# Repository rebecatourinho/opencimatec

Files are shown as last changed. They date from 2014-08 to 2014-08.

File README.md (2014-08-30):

opencimatec
===========

Neste repositório encontram-se os arquivos referentes ao projeto open source hardware (OSH) do sistema embarcado voltado à instrumentação eletrônica proposto e desenvolvido pela engenheira eletricista Rebeca Tourinho do SENAI CIMATEC - Salvador, Brasil.

In this repository can be found all project files of the open source hardware (OSH) electronics instrumentation embedded system suggested and developed by Rebeca Tourinho, electrical engineer of SENAI CIMATEC - Salvador, Brazil.

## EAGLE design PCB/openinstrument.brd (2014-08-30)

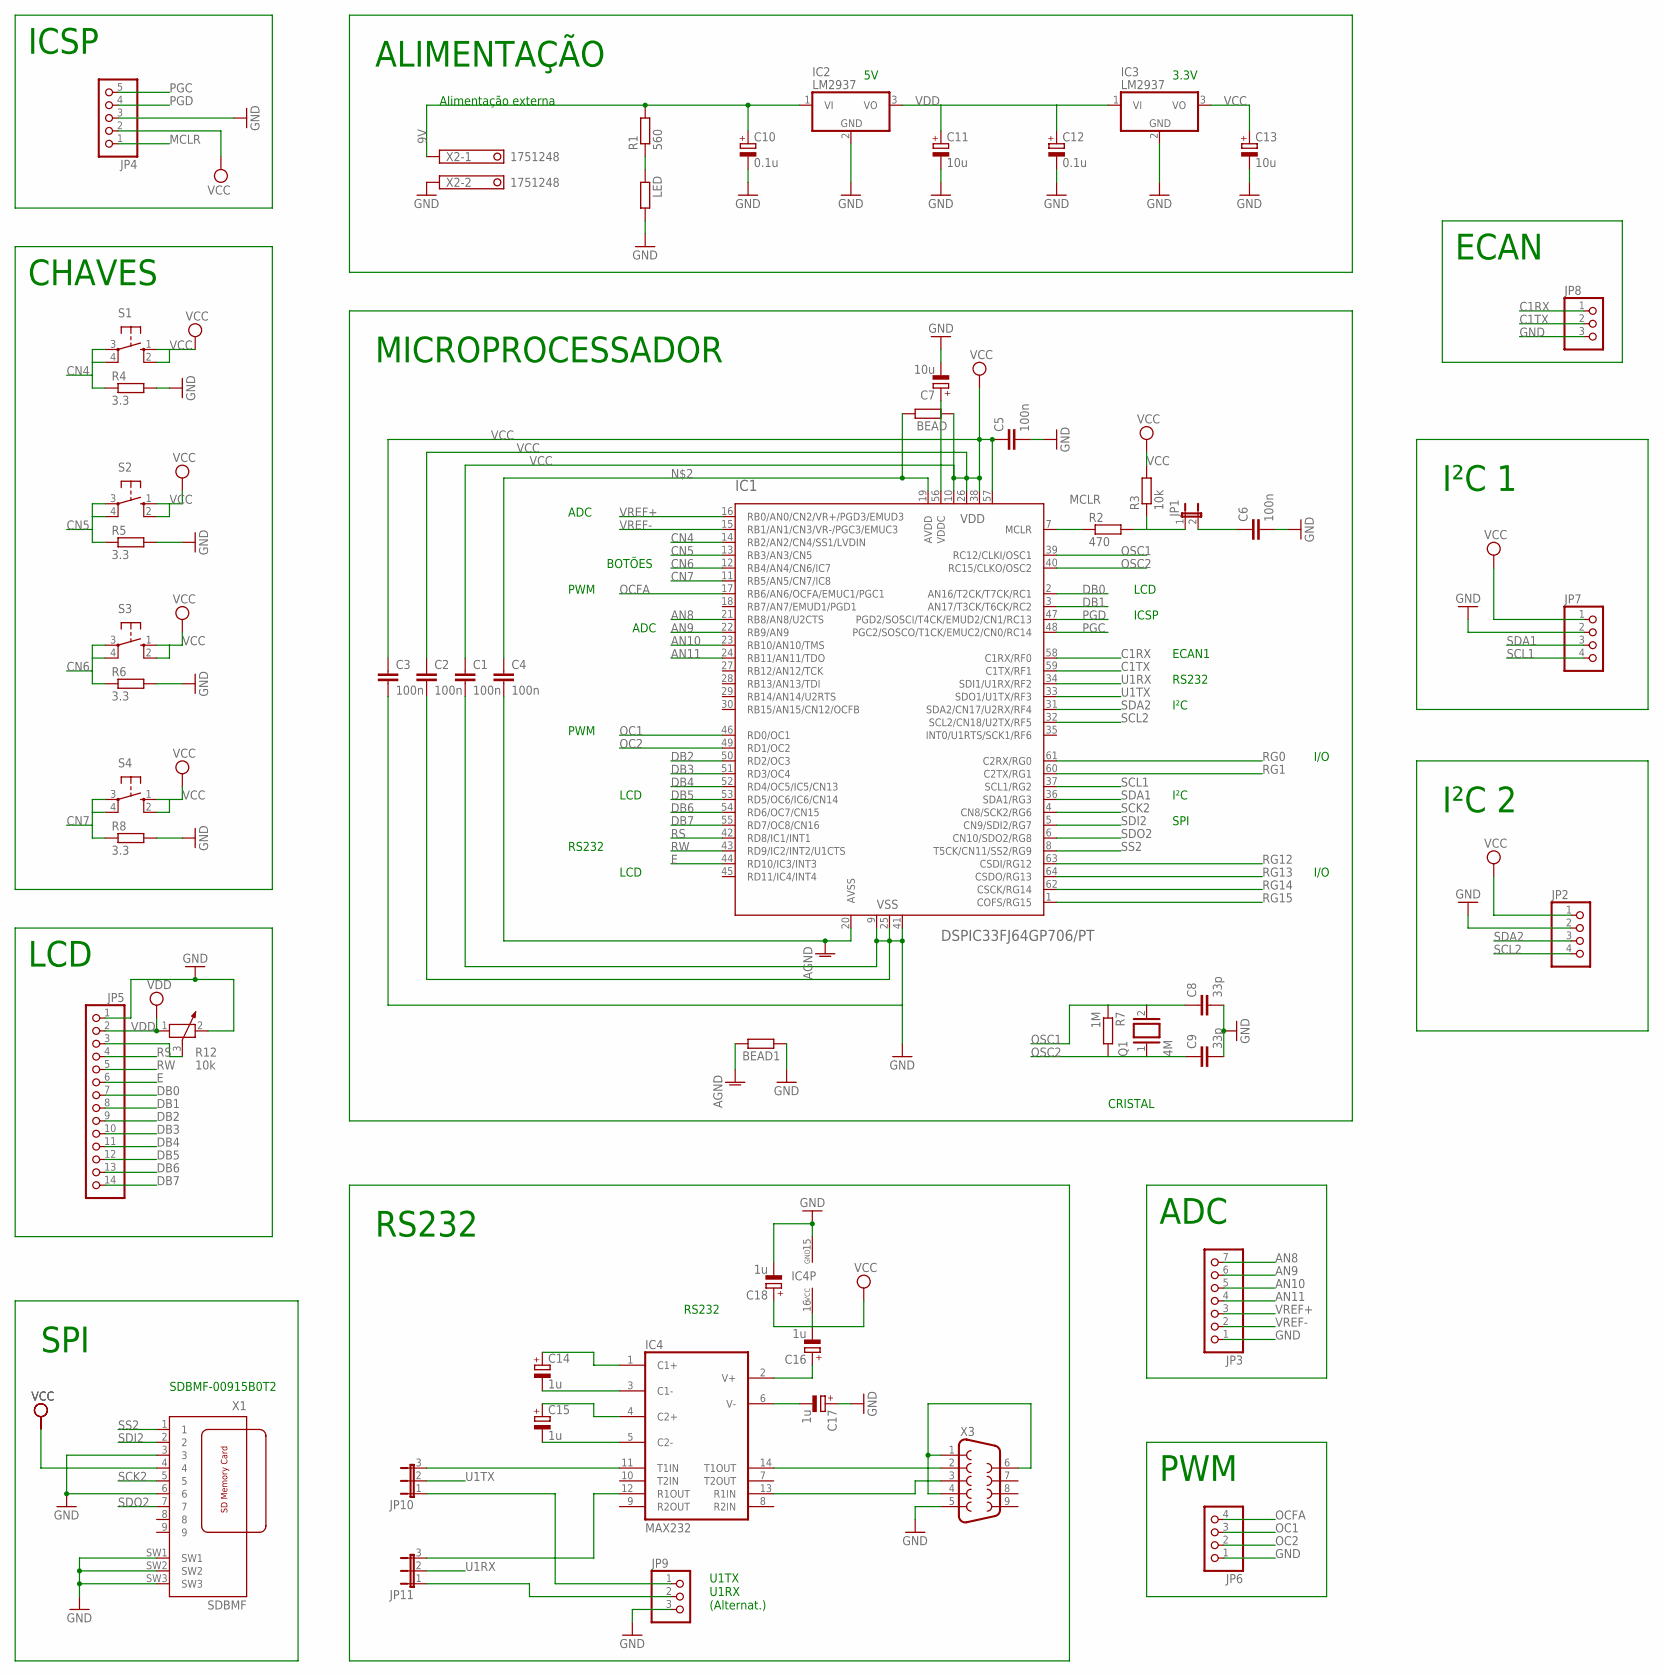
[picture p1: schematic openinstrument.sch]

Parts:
BEAD, BEAD1: R-EU_R0805; R0805
C1, C2, C3, C4, C5, C6: 100n; C0805
C7, C11, C13: 10u; E2,5-5
C8, C9: 33p; C0805
C10, C12: 0.1u; E2,5-5
C14, C15, C16, C17, C18: 1u; E2,5-5
IC1: DSPIC33FJ64GP706/PT; TQFP64-10X10
IC2, IC3: LM2937; TO263-3
IC4: MAX232; DIL16
JP1: JP1E; JP1
JP2, JP6, JP7: PINHD-1X4; 1X04
JP3: PINHD-1X7; 1X07
JP4: PINHD-1X5; 1X05
JP5: PINHD-1X14; 1X14
JP8, JP9: PINHD-1X3; 1X03
JP10, JP11: JP2E; JP2
LED: R-EU_R0805; R0805
Q1: 4M; QS
R1: 560; R0805
R2: 470; R0805
R3: 10k; R0805
R4, R5, R6, R8: 3.3; R0805
R7: 1M; R0805
R12: 10k; PT-10S
S1, S2, S3, S4: 10-XX; B3F-10XX
X1: SDBMF; SDBMF-009XXBXX2
X2: 1751248
X3: F09H

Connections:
9V: C10.+, IC2.1 (VI), R1.2, X2.1
AGND: BEAD1.2, C4.2, IC1.20 (AVSS)
AN8: IC1.21 (RB8/AN8/U2CTS), JP3.7
AN9: IC1.22 (RB9/AN9), JP3.6
AN10: IC1.23 (RB10/AN10/TMS), JP3.5
AN11: IC1.24 (RB11/AN11/TDO), JP3.4
C1RX: IC1.58 (C1RX/RF0), JP8.1
C1TX: IC1.59 (C1TX/RF1), JP8.2
CN4: IC1.14 (RB2/AN2/CN4/SS1/LVDIN), R4.1, S1.3, S1.4 (P1)
CN5: IC1.13 (RB3/AN3/CN5), R5.1, S2.3, S2.4 (P1)
CN6: IC1.12 (RB4/AN4/CN6/IC7), R6.1, S3.3, S3.4 (P1)
CN7: IC1.11 (RB5/AN5/CN7/IC8), R8.1, S4.3, S4.4 (P1)
DB0: IC1.2 (AN16/T2CK/T7CK/RC1), JP5.7
DB1: IC1.3 (AN17/T3CK/T6CK/RC2), JP5.8
DB2: IC1.50 (RD2/OC3), JP5.9
DB3: IC1.51 (RD3/OC4), JP5.10
DB4: IC1.52 (RD4/OC5/IC5/CN13), JP5.11
DB5: IC1.53 (RD5/OC6/IC6/CN14), JP5.12
DB6: IC1.54 (RD6/OC7/CN15), JP5.13
DB7: IC1.55 (RD7/OC8/CN16), JP5.14
E: IC1.44 (RD10/IC3/INT3), JP5.6
GND: BEAD1.1, C1.2, C2.2, C3.2, C5.2, C6.2, C7.-, C8.2, C9.2, C10.-, C11.-, C12.-, C13.-, C17.+, C18.-, IC1.9 (VSS), IC1.25 (VSS), IC1.41 (VSS), IC2.2 (GND), IC3.2 (GND), IC4.15 (GND), JP2.2, JP3.1, JP4.3, JP5.1, JP6.1, JP7.2, JP8.3, JP9.3, LED.2, R4.2, R5.2, R6.2, R8.2, R12.2, X1.3, X1.6, X1.SW1, X1.SW2, X1.SW3, X2.2, X3.5
MCLR: JP4.1, R2.1
unnamed: JP5.3, R12.3
unnamed: BEAD.2, C4.1, IC1.19 (AVDD)
unnamed: JP1.1, R2.2, R3.1
unnamed: C6.1, JP1.2
unnamed: IC4.14 (T1OUT), X3.2
unnamed: C14.-, IC4.3 (C1-)
unnamed: C14.+, IC4.1 (C1+)
unnamed: C15.-, IC4.5 (C2-)
unnamed: C7.+, IC1.56 (VDDC)
unnamed: LED.1, R1.1
unnamed: C15.+, IC4.4 (C2+)
unnamed: C16.+, IC4.2 (V+)
unnamed: C17.-, IC4.6 (V-)
unnamed: IC4.13 (R1IN), X3.3
unnamed: X3.1, X3.4, X3.6
unnamed: IC4.12 (R1OUT), JP11.3
unnamed: JP9.1, JP10.1
unnamed: IC4.11 (T1IN), JP10.3
unnamed: JP9.2, JP11.1
OC1: IC1.46 (RD0/OC1), JP6.3
OC2: IC1.49 (RD1/OC2), JP6.2
OCFA: IC1.17 (RB6/AN6/OCFA/EMUC1/PGC1), JP6.4
OSC1: C8.1, IC1.39 (RC12/CLKI/OSC1), Q1.2, R7.1
OSC2: C9.1, IC1.40 (RC15/CLKO/OSC2), Q1.1, R7.2
PGC: IC1.48 (PGC2/SOSCO/T1CK/EMUC2/CN0/RC14), JP4.5
PGD: IC1.47 (PGD2/SOSCI/T4CK/EMUD2/CN1/RC13), JP4.4
RG0: IC1.61 (C2RX/RG0)
RG1: IC1.60 (C2TX/RG1)
RG12: IC1.63 (CSDI/RG12)
RG13: IC1.64 (CSDO/RG13)
RG14: IC1.62 (CSCK/RG14)
RG15: IC1.1 (COFS/RG15)
RS: IC1.42 (RD8/IC1/INT1), JP5.4
RW: IC1.43 (RD9/IC2/INT2/U1CTS), JP5.5
SCK2: IC1.4 (CN8/SCK2/RG6), X1.5
SCL1: IC1.37 (SCL1/RG2), JP7.4
SCL2: IC1.32 (SCL2/CN18/U2TX/RF5), JP2.4
SDA1: IC1.36 (SDA1/RG3), JP7.3
SDA2: IC1.31 (SDA2/CN17/U2RX/RF4), JP2.3
SDI2: IC1.5 (CN9/SDI2/RG7), X1.2
SDO2: IC1.6 (CN10/SDO2/RG8), X1.7
SS2: IC1.8 (T5CK/CN11/SS2/RG9), X1.1
U1RX: IC1.34 (SDI1/U1RX/RF2), JP11.2
U1TX: IC1.33 (SDO1/U1TX/RF3), JP10.2
VCC: BEAD.1, C1.1, C2.1, C3.1, C5.1, C13.+, C16.-, C18.+, IC1.10 (VDD), IC1.26 (VDD), IC1.38 (VDD), IC1.57 (VDD), IC3.3 (VO), IC4.16 (VCC), JP2.1, JP4.2, JP7.1, R3.2, S1.1 (S), S1.2 (S1), S2.1 (S), S2.2 (S1), S3.1 (S), S3.2 (S1), S4.1 (S), S4.2 (S1), X1.4
VDD: C11.+, C12.+, IC2.3 (VO), IC3.1 (VI), JP5.2, R12.1
VREF+: IC1.16 (RB0/AN0/CN2/VR+/PGD3/EMUD3), JP3.3
VREF-: IC1.15 (RB1/AN1/CN3/VR-/PGC3/EMUC3), JP3.2

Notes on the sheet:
ICSP
LCD
SDBMF-00915B0T2
Alimentação externa
3.3V
ECAN1
RS232
I²C
SPI
PWM
ADC
BOTÕES
I/O
CRISTAL
CHAVES
ECAN
U1TX U1RX (Alternat.)
ALIMENTAÇÃO
MICROPROCESSADOR
I²C 1
I²C 2

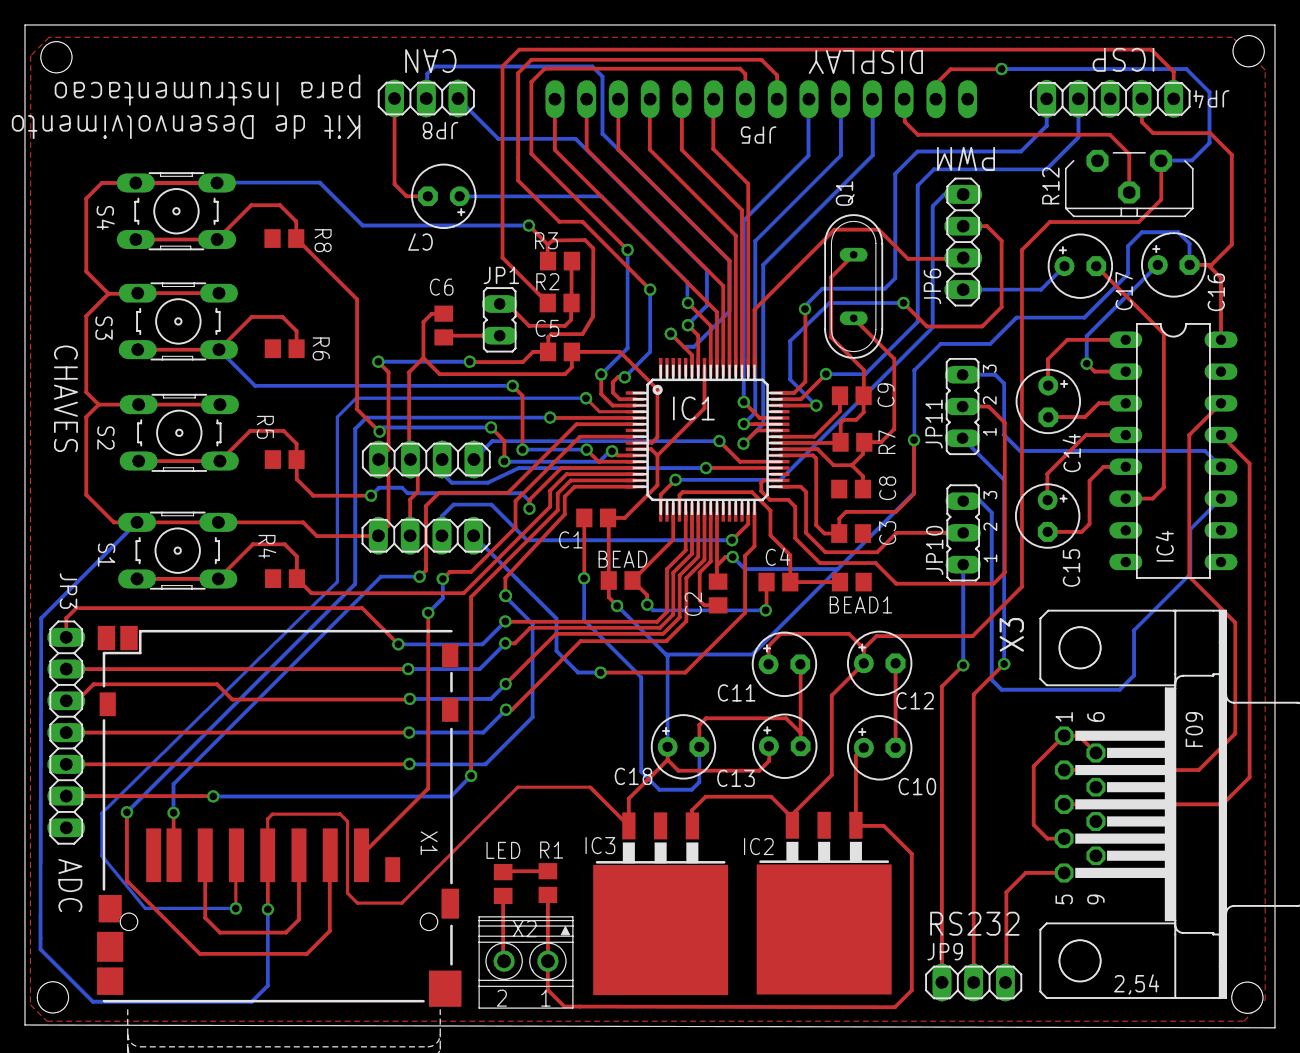
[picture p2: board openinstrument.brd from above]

Board: 2 copper layers, 100.0 x 80.2 mm, 53 parts (1 on the bottom side), 65 nets.

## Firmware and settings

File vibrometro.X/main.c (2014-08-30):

/* File:   main.c
 * Author: rebecatourinho
 * Created on March 24, 2014, 10:29 AM
 * Modified on May 23, 2014, 09:55 PM
 */

#include<p33FJ64GP706.h>
#include "timer.h"
#include "i2c.h"
#include "lcd.h"
#include "menu.h"

//Configurations Bits
//Flash Boot Segmentation
_FBS(BWRP_WRPROTECT_OFF & BSS_NO_BOOT_CODE & RBS_NO_BOOT_RAM);  //default 0xFFFF
//Flash Secure Segmentation
_FSS(SWRP_WRPROTECT_OFF & SSS_NO_SEC_CODE & RSS_NO_SEC_RAM);    //default 0xFFFF
//General Segmentation
_FGS(GWRP_OFF & GSS_OFF);                                      //default 0x/FFFF
//Oscillator source and start-up
_FOSCSEL(FNOSC_PRI & IESO_ON);                 //Primary (XT, HS, EC) oscillator
//Oscillator Mode
_FOSC(POSCMD_XT & OSCIOFNC_OFF & FCKSM_CSDCMD);             //XT Oscillator Mode
//Watchdog timer
_FWDT(WDTPOST_PS1 & WDTPRE_PR32 & WINDIS_OFF & FWDTEN_OFF);            //WTD off
//Power-up timer delay time
_FPOR(FPWRT_PWR128);                                           //default 0x/FFFF
//ICD Communication Channel
_FICD(ICS_PGD1 & JTAGEN_OFF);         //Communicate on PGC1/EMUC1 and PGD1/EMUD1

//Vetores de medições XYZ
/*extern signed int eixoX[32];
extern signed int eixoY[32];
extern signed int eixoZ[32];
*/


int main(void)
{

    //Configura e habilita comunicação I2C1
    config_comI2C1();
    
    //Sequência de configuração do ADXL345: Registrador e comando
    config_sensor(0x2C,0x0F);      //Data rate=3200Hz BW=1600Hz, normal power
    config_sensor(0x31,0x0B);      //Full-bit, 16g, 3.9mg/LSB
    //config_sensor(0x31,0x08);    //Full, 2g
    //config_sensor(0x31,0x09);    //Full, 4g
    config_sensor(0x2D,0x08);      //Modo measurement


    //inicia_lcd();
    inicia_menu();
    
/*
    while(1)
    {
        le_sensor();                //Amostra e exibe na tela
        //delay_ms(80);              //taxa de amostragem
      
    }
*/
 
    
}

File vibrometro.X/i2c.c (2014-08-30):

#include<p33FJ64GP706.h>
#include "i2c.h"
#include "timer.h"
#include "lcd.h"
#define TAMANHO 512


int cont_data;                 //Contador para acessar e ordenar dados
int endr_ini;                  //Variável que contém endereço inicial
char dados[6];                 //Vetor para armazenar DATA X0/X1/Y0/Y1/Z0/Z1
int cont_conc,cont_eixo;       //Contadores auxiliares
signed int eixoX[TAMANHO];          //Vetor de medições concatenadas em X
signed int eixoY[TAMANHO];          //Vetor de medições concatenadas em Y
signed int eixoZ[TAMANHO];          //Vetor de medições concatenadas em Z
signed int eixoZ_aux;
signed int eixoY_aux;
signed int eixoX_aux;
char medXYZ[7];                //Medida de 5 dígitos + '0' + sinal


//Configuração do I2C1
void config_comI2C1 (void)
{
    ODCGbits.ODCG2=1;          //Configura SCL1/RG2 como Open Drain
    ODCGbits.ODCG3=1;          //Configura SDA1/RG3 como Open Drain
    I2C1CONbits.I2CEN = 1;     //Habilita o módulo I2C do dsPIC
    I2C1BRG = BAUD;            //Configura baud rate de 100 KHz para XT=4MHz
    IEC1bits.MI2C1IE = 1;      //Habilita a interrupção do master
    IEC1bits.SI2C1IE = 1;      //Habilita a interrupção do slave
}


//Comunicação como mestre em um sistema de único mestre
void config_sensor (int registrador, int comando)
{
    for (cont_data=0;cont_data<6;cont_data++)
    {

        I2C1CONbits.SEN = 1;                    //Start
        while(I2C1CONbits.SEN == 1);

        I2C1TRN = 0xA6;                         //Slave Address + Write=0
        while(I2C1STATbits.TRSTAT == 1);

        I2C1TRN = registrador;                  //Endereço do registrador
        while(I2C1STATbits.TRSTAT == 1);

        I2C1TRN = comando;                      //Comando
        while(I2C1STATbits.TRSTAT == 1);

        I2C1CONbits.PEN = 1;                    //Stop
        while(I2C1CONbits.PEN == 1);

    }

}

//Função que converte medida em ASCII com sinal +/-
void num2char (signed int medida)
{
    medXYZ[6]=0;                               //Caractere de parada
    int cont_char=5;                           //Num máximo de algarismos, 16g
    medXYZ[0]='+';                             //Sinal no display

    if (medida<0){
        medida = medida*(-1);                  //Obtém valor positivo (absoluto)
        medXYZ[0]='-';                         //Altera o sinal para negativo
    }

    while(cont_char>0){
        medXYZ[cont_char] = medida%10 + 0x30;  //Resto da divisão + ASCII
        medida = medida/10;                    //Remove uma dezena
        cont_char--;
    }

}


//Função que realiza a leitura de uma medida XYZ e exibe no display
void le_sensor (void)
{
    for (cont_data=0;cont_data<6;cont_data++)
    {
        
        I2C1CONbits.SEN = 1;                    //Start condition
        while(I2C1CONbits.SEN == 1);
        //I2C1STATbits.BCL = 0;
        I2C1TRN = 0xA6;                         //Slave Address + Write=0

        while(I2C1STATbits.TRSTAT == 1);

        endr_ini = 0x32;                        //Endereço inicial, DATA_X0
        I2C1TRN = endr_ini + cont_data;
        while(I2C1STATbits.TRSTAT == 1);

        I2C1CONbits.RSEN = 1;                   //Repeated start
        while(I2C1CONbits.RSEN == 1);
        
        I2C1TRN = 0xA7;                         //Address + Read=1
        while(I2C1STATbits.TRSTAT == 1);
        
        I2C1CONbits.RCEN = 1;                   //Habilita recepção
        while(I2C1CONbits.RCEN == 1);
        dados[cont_data] = I2C1RCV;             //Armazena dado recebido

        I2C1CONbits.ACKDT = NACK;               //Envia NACK
        I2C1CONbits.ACKEN = 1;
        while(I2C1CONbits.ACKEN == 1);
        I2C1CONbits.PEN = 1;                    //Stop condition
        while(I2C1CONbits.PEN == 1);
        
    }

    //Concatena medida de 16 bits em X e converte para mg
    eixoX[cont_eixo] = dados[1];
    eixoX[cont_eixo] = eixoX[cont_eixo] << 8;
    eixoX_aux=dados[0]&0x00FF;
    eixoX[cont_eixo] = (eixoX[cont_eixo]|eixoX_aux);
    eixoX[cont_eixo] = eixoX[cont_eixo]*SF_APROX;

    num2char(eixoX[cont_eixo]);
    comandolcd(0x80);               //1a linha
    escrevetexto("X");
    escrevetexto(medXYZ);

    //Concatena medida de 16 bits em Y
    eixoY[cont_eixo] = dados[3];
    eixoY[cont_eixo] = eixoY[cont_eixo] << 8;
    eixoY_aux=dados[2]&0x00FF;
    eixoY[cont_eixo] = (eixoY[cont_eixo]|eixoY_aux);
    eixoY[cont_eixo] = eixoY[cont_eixo]*SF_APROX;
    
    num2char(eixoY[cont_eixo]);
    escrevetexto(" Y");
    escrevetexto(medXYZ);

    //Concatena medida de 16 bits em Z
    eixoZ[cont_eixo] = dados[5];
    eixoZ[cont_eixo] = eixoZ[cont_eixo] << 8;
    eixoZ_aux=dados[4]&0x00FF;
    eixoZ[cont_eixo] = (eixoZ[cont_eixo]|eixoZ_aux);
    eixoZ[cont_eixo] = eixoZ[cont_eixo]*SF_APROX;

    comandolcd(0xC0);               //2a linha
    num2char(eixoZ[cont_eixo]);
    escrevetexto("Z");
    escrevetexto(medXYZ);

    //Incrementa o contador a cada leitura
    cont_eixo++;

    //Limpa contador após vetor ser preenchido completamente
    if (cont_eixo >= TAMANHO){
        cont_eixo = 0;
    }


}


//Qual a necessidade de implementar essas interrupções?
//Master Events
void __attribute__((__interrupt__,__auto_psv__))  _MI2C1Interrupt(void)
{
   
   IFS1bits.MI2C1IF = 0;            //Limpa MI2CxIF
   if(I2C1STATbits.RBF==1)          //RBF é zerado após CPU ler buffer
   {
       //cont_data=cont_data;       //Não sei o porquê desta linha
   }
   
}

//Slave Events
void __attribute__((__interrupt__,__auto_psv__))  _SI2C1Interrupt(void)
{
   IFS1bits.SI2C1IF = 0;
}



 /* Complemento de 2
  *
    if ((eixoX[cont_eixo] & 0xF000) == 0xF000){
        eixoX[cont_eixo] = (~(eixoX[cont_eixo] + 1))*(-1);
    }
    */
